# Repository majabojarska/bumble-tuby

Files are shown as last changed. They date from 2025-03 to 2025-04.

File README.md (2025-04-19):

# Bumble Tuby Guitar Amplifier




This is a relatively simple, hybrid guitar amplifier, made as a hobby project.
To me it's mostly about learning, having fun, and building something tangible.

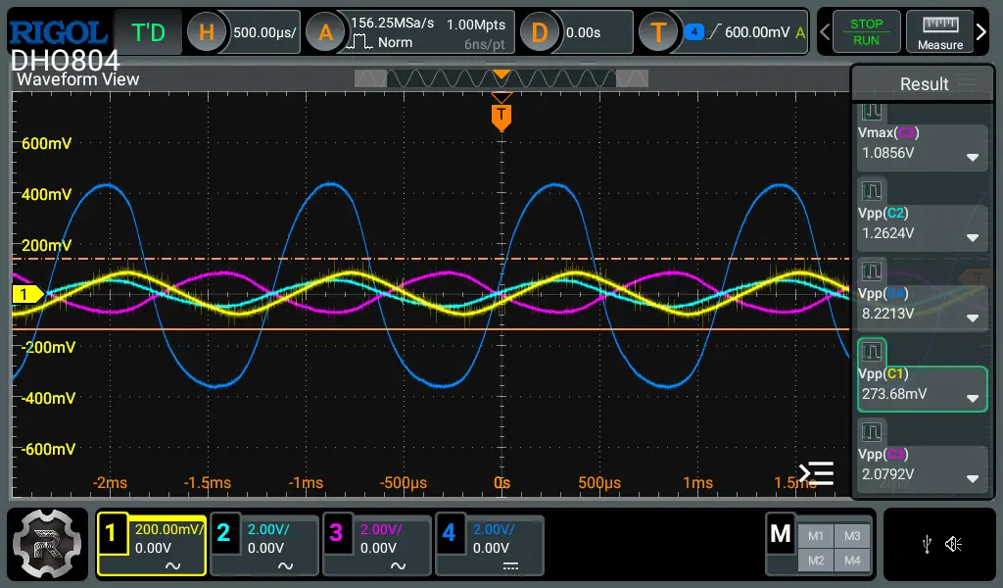
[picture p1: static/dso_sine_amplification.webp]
DSO capture of amplification stage outputs


## Features

- Runs off of a single 12V DC supply
- Pre-amp based on the 12AU7 vacuum tube
- FX loop
- Tone control section
- Line in
- Solid state power amplifiers (headphones, speaker)
  - Class D mono speaker amp
  - Class A stereo headphone amp

Schematic

### Bill of materials

> [!NOTE]  
> This section is yet to be populated.

## To-do

### Circuit design

- [x] Add headphone output.
- [x] Add effects loop:
  - FX send can be driven directly from the 2nd tube stage.
  - FX return needs a buffer before feeding into the power amp section. Can use the second half of the NE5532 for this.
  - What about operation modes? With/without effects loop. This would require a SPDT switch to either send the pre-amped signal into the effects chain, or directly into the buffer.
- [x] Add bypass capacitors on power supply lines:
  - LM386: 10uF, 100nF
  - opamps: 10uF, 100nF
- [x] Add power switch, LED
- [x] Consider poweramp alternatives
  - TPA3110
- [x] Make buffer bias voltage adjustable
- [x] Fix tube biasing
- [x] Buffer triode outputs (plates)
- [x] Mute speaker PA when headphone jack plugged in
- [x] Add headphone PA
- [x] Add gain adjustment for the power section (LM386 pins 1-8)
- [x] Split design into separate subschematics
  - How to express connections?
  - [Hierarchical sheets in KiCad](https://docs.kicad.org/9.0/en/eeschema/eeschema.html#drawing-hierarchical-sheets)
- [x] Add stereo line-in, [signal mixing](https://electronics.stackexchange.com/questions/103435/naively-mixing-two-or-perhaps-more-audio-signals)
- [x] Attenuate FX send 20x, and then on return amplify it by 20x
  - Floor pedals can't handle the 8Vpp the preamp outputs
  - The whole FX section should by itself have unity gain, if the send and return are shorted.
- [x] Add split-rail opamp bias source
- [ ] Split design into multiple sheets
- [ ] Add a tone control section.
  - Big muff style single-pot tone control seems nice and simple.
  - After tube, before output buffer? Alternatively, right after gain stage, before first triode.
- [ ] Add screw terminals for vacuum tube connections
- [ ] Does this require ripple rejection?
- [ ] Revisit tube input biasing, something seems off. Verify on breadboard.
- [ ] Simulate pre-amp in SPICE
- [ ] Design perfboard layouts

### CI

- [ ] Render BOM into README, as a Markdown table.
- [ ] Auto update schematic date during artifact update workflow.

## Credits

This design was inspired by:

- [Ruby Tuby](https://tagboardeffects.blogspot.com/2014/10/ruby-tuby.html)
  amplifier design.
- [Tube Cricket](https://beavisaudio.com/projects/TubeCricket/)

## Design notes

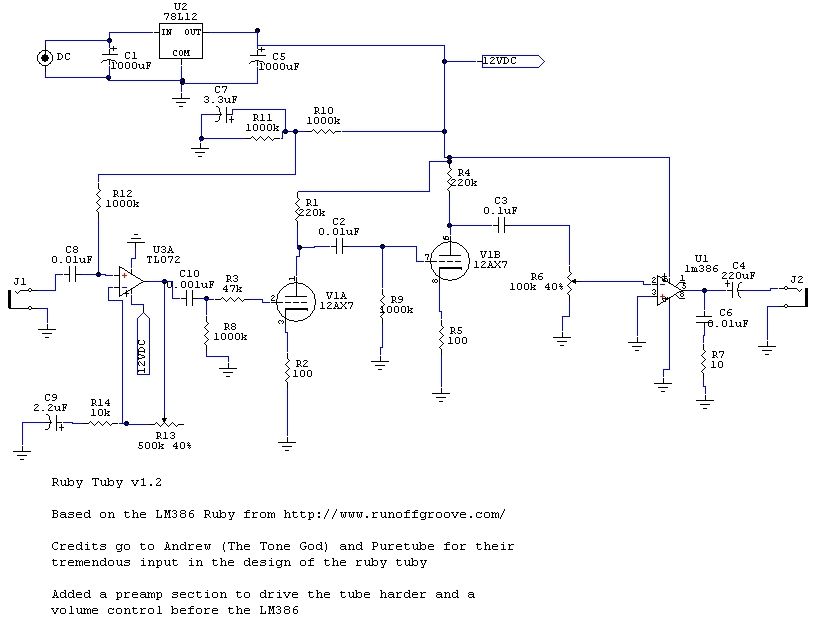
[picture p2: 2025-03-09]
static/ruby_tuby_original.jpg

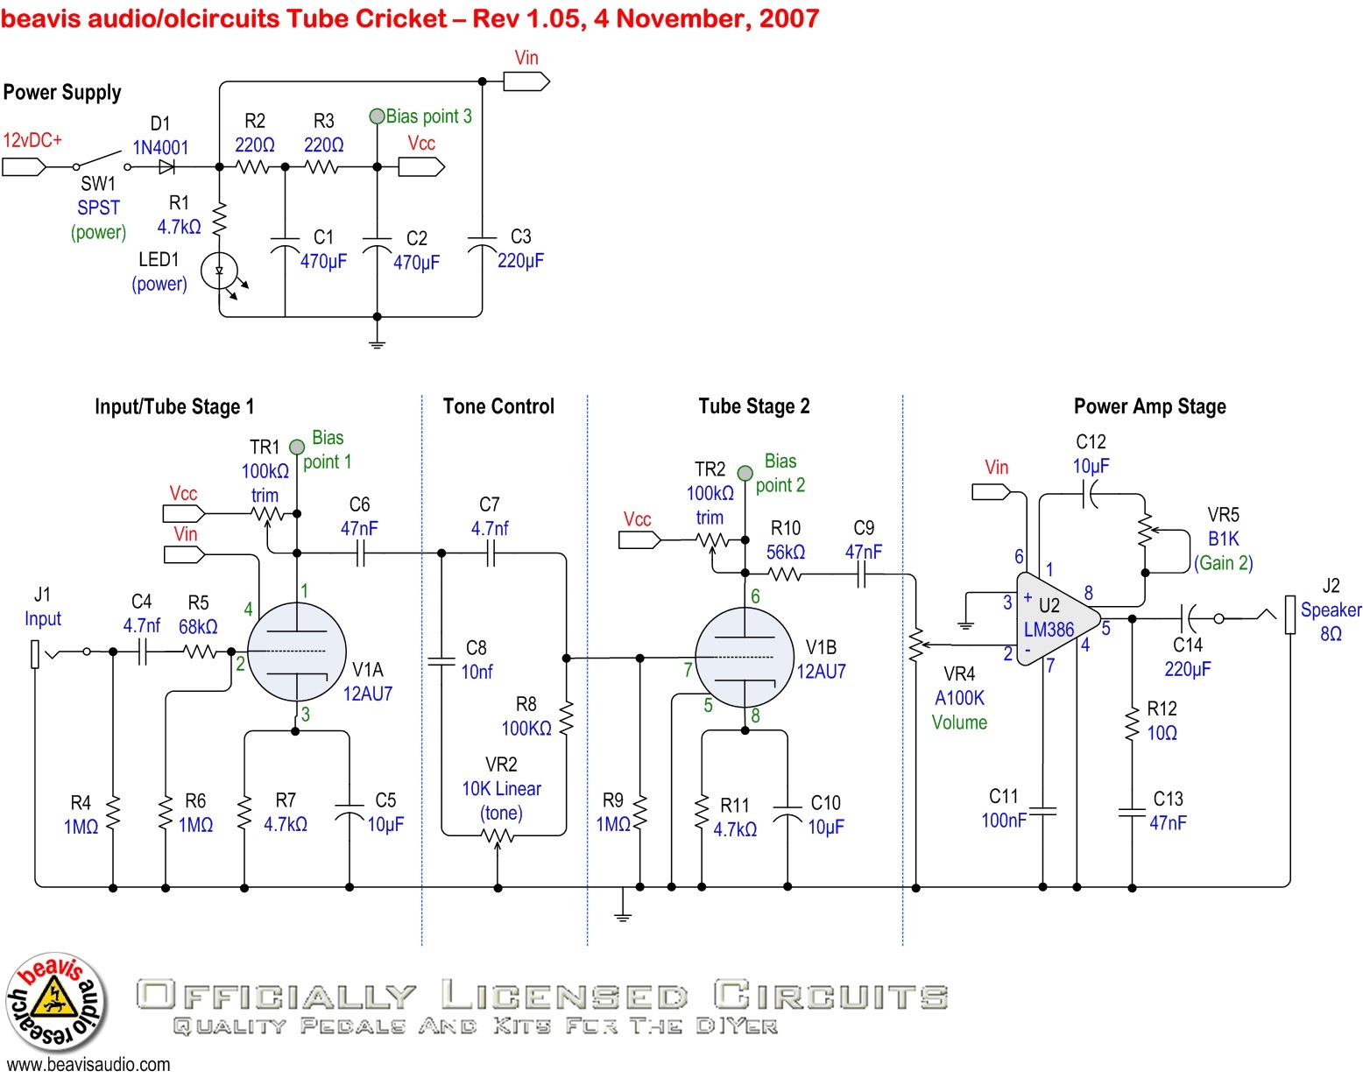
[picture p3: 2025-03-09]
static/tube_cricket.jpg

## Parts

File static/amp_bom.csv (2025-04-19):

Refs | Value | Footprint | Qty | DNP
C3,C4,C5,C6,C9,C29,C30 | 1uF |  | 7
C7,C10,C22,C25,C28 | 10uF |  | 5
C8,C11,C20 | 10nF |  | 3
C12,C13,C16,C17,C21,C27,C34 | 100nF |  | 7
C14,C15 | 100uF |  | 2
C18,C19 | 220uF |  | 2
C23,C24 | 47nF |  | 2
C26 | 2.2uF |  | 1
C33 | 1000uF |  | 1
D1 | LED amber |  | 1
D2 | LED blue |  | 1
J1 | LO Input |  | 1
J2 | Headphones |  | 1
J3 | HI Input |  | 1
J4 | Speaker 8Ω |  | 1
J5 | FX Send |  | 1
J6 | FX Return |  | 1
Q1 | S8050 |  | 1
R2,R12,R14,R16,R21,R25,R27,R31 | 1M |  | 8
R3,R4,R5,R6,R7,R8,R9,R10,R11,R18,R19,R29,R30,R35 | 10K |  | 14
R13,R15,R33,R34 | 220K |  | 4
R17,R32 | 4K7 |  | 2
R20,R22 | 47K |  | 2
R23,R24 | 10 |  | 2
R26,R28 | 100 |  | 2
RV2 | 50K log |  | 1
RV3 | 500K lin |  | 1
RV4 | 100K |  | 1
RV5 | 10k |  | 1
SW1 | PWR |  | 1
SW2 | FX Enable/Bypass |  | 1
U1,U2 | TL074 |  | 2
U3,U4 | LM386 |  | 2
U5 | ~ |  | 1
U6 | TL072 |  | 1
V1 | 12AX7 | Valve:Valve_Noval_P | 1

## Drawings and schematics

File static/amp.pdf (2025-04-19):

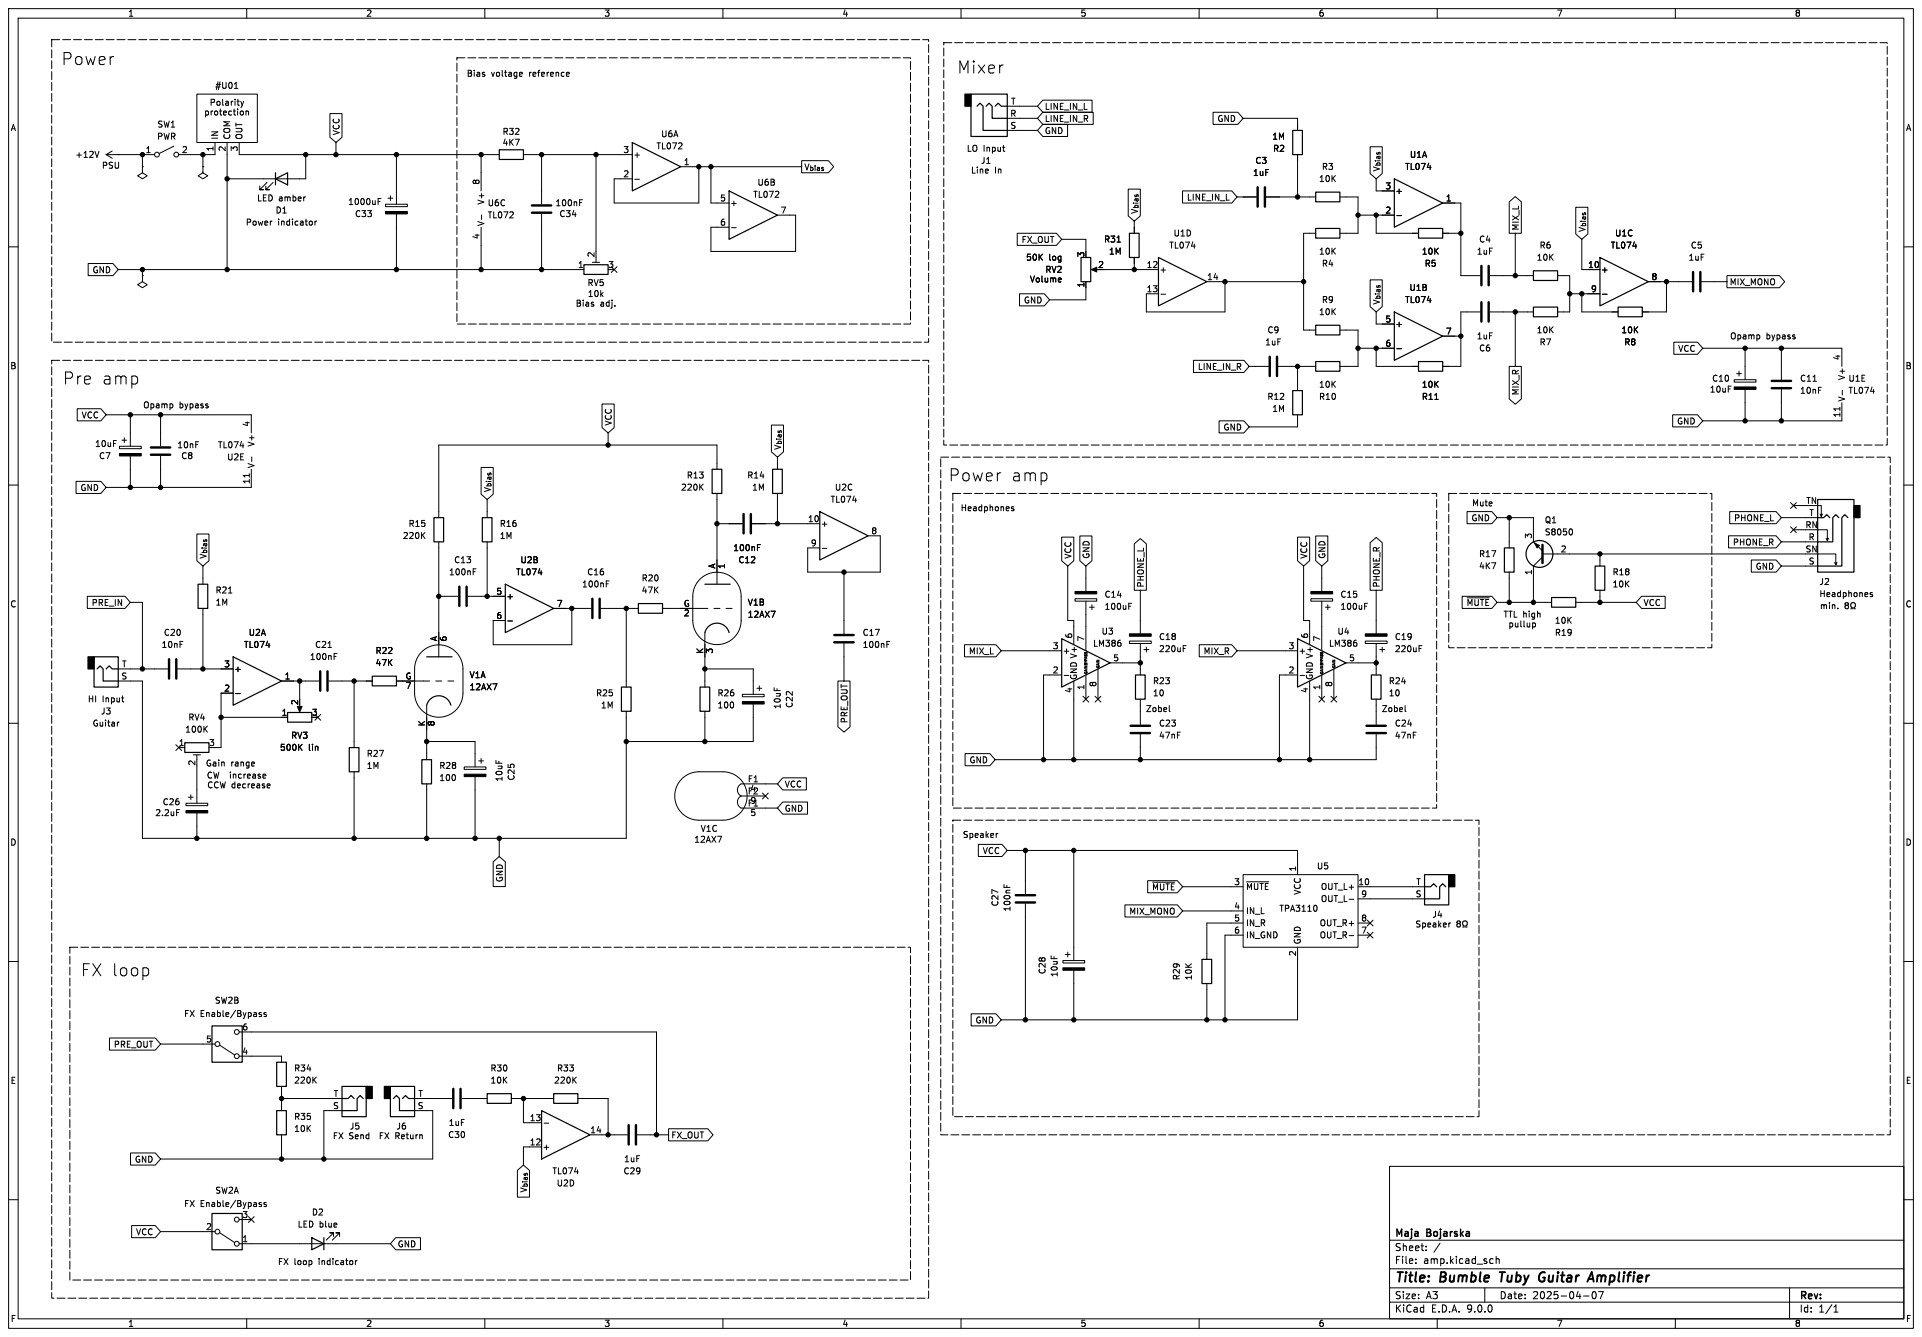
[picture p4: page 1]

Opamp bypass Zobel Mixer

LO Input Line In

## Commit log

2025-03-09 Initial circuit design (#2)
    - Adds project description in README.md
    - Populates schematic with initial circuit design
    - Includes headphone output
    - Adds future design to-dos
    - Credits other designs influencing this project
    - Extends ERC pre-commit triggers to any kicad file.
    [amp.kicad_pcb, amp.kicad_sch, amp_bom.csv]
2025-03-09 Improve artifact generation flow (#3)
    - Artifact generation opens a pull request instead of pushing to `main`.
    - The pull request is opened only if there are relevant changes. Non-relevant changes would be a diff consisting of "creation date" changes.
    - BOM generation also emits a markdown file containing the BOM table, generated from the CSV BOM.
2025-03-10 Add FX loop (#10)
    [amp.kicad_sch, amp_bom.csv]
2025-03-10 Add bypass caps (#11)
    [amp.kicad_sch, amp_bom.csv]
2025-03-11 Add power switch and led indicators (#12)
    Also replaces the FX loop SPDT switch with a DPDT, one for the signal,
    one for the LED indicator power.
    [amp.kicad_sch, amp_bom.csv]
2025-03-12 Schematic improvements (#14)
    - Replace remaining 12V with VCC
    - Schematic placement
    - TODO updates
    [amp.kicad_sch, amp_bom.csv]
2025-03-16 Add missing bias after FX loop return buffer (#15)
    [amp.kicad_sch, amp_bom.csv]
2025-03-16 Make diagrams black and white (#16)
    Better for printing and displaying on e-inks
2025-03-24 Fix: Remove bias after the FX loop return buffer (#17)
    [amp.kicad_sch, amp_bom.csv]
2025-04-03 Add TPA3110 module symbol (#18)
    ![image](https://github.com/user-attachments/assets/f8b43d61-f9f9-42f1-95b0-69642c91a372)
2025-04-04 Make input gain range adjustable (#19)
    ![image](https://github.com/user-attachments/assets/c34fa773-1671-44be-a96f-30affde28c4a)
    [amp.kicad_sch, amp_bom.csv]
2025-04-04 Use TL072 instead of NE5532 (#21)
    [amp.kicad_sch, amp_bom.csv]
2025-04-04 Make bias voltage adjustable (#22)
    ![image](https://github.com/user-attachments/assets/7d272d7a-218c-4b01-b36d-8e7ddcb458f7)
    [amp.kicad_sch, amp_bom.csv]
2025-04-04 Use TPA3110 (#23)
    ![image](https://github.com/user-attachments/assets/09bd7c46-21d9-4840-b3ab-6c87bac1cede)
    [amp.kicad_sch, amp_bom.csv]
2025-04-04 Fixup TPA3110 changes - botched wiring (#24)
    [amp.kicad_sch]
2025-04-04 Buffer triode outputs (#25)
    ![image](https://github.com/user-attachments/assets/d7fb1445-c9db-46b0-b5f0-927bbe05cb8b)
    [amp.kicad_sch, amp_bom.csv]
2025-04-05 Use TL074 instead of 2xTL072 for preamp (#28)
    [amp.kicad_sch, amp_bom.csv]
2025-04-05 Mute speaker PA when headphones are plugged in (#29)
    Also includes some layout/readability improvements
    [amp.kicad_sch, amp_bom.csv]
2025-04-05 Add amplification stage DSO capture image to README (#30)
2025-04-06 Add polarity protection (#33)
    Also adds a bunch of layout reworks, uses netlist labels.
    [amp.kicad_sch]
2025-04-06 Split sections, label I/O netlists (#34)
    [amp.kicad_sch, amp_bom.csv]
2025-04-06 Headphone PA, line-in support, active signal mixing, (#35)
    [amp.kicad_sch, amp_bom.csv]
2025-04-06 Fix input opamp gain pot type (log->lin) (#38)
    [amp.kicad_sch, amp_bom.csv]
2025-04-06 Fix U1A output coupling pot 1->10nF (#39)
    [amp.kicad_sch, amp_bom.csv]
2025-04-08 Move opamp bias source to power section (#41)
    ![image](https://github.com/user-attachments/assets/52923ac5-943d-44d2-a7b1-d4a0f699007a)
    [amp.kicad_sch, amp_bom.csv]
2025-04-08 Replace 2xNE5532 in mixer with 1xTL074 (#42)
    [amp.kicad_sch, amp_bom.csv]
2025-04-08 Update KiCad artifacts (#40)
    ## Beep boop, fresh artifacts 🤖.
    KiCad project sources have changed, fresh artifacts incoming ♻️!
    Auto-generated by [create-pull-request][1]
    [1]: https://github.com/peter-evans/create-pull-request
2025-04-08 Improve tube biasing (#49)
    Try out Tube Cricket style tube biasing
    https://beavisaudio.com/projects/TubeCricket/
    [amp.kicad_sch, amp_bom.csv]
2025-04-08 Update KiCad artifacts (#50)
    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
2025-04-19 Fixes prototype (#51)
    Okay so around a week ago I made some changes in my breadboard
    prototype, applied some of them here, got a week-long break, and now I
    barely remember what happened. Fortunately, the SVG diff and commit
    history explain a lot, so here it goes:
    - Fixes tube biasing, or at least gets it to a much better place. The
    previous plate/cathode resistors configuration caused the triode outputs
    to be way too biased towards `VCC`, resulting in a narrow dynamic range
    and causing the tube stages to clip easily against the ceiling.
    - FX loop:
    - send is now attenuated by 22x and amplified by 22x upon return. This
    is due to the preamp reaching close to $10V_{pp}$, which most pedal
    effects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
    [amp.kicad_sch, amp_bom.csv]
2025-04-19 Update KiCad artifacts (#52)
    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
2025-04-19 Active opamp bias voltage reference (#53)
    Reworks the bias reference voltage dividers into a single, opamp-based
    voltage reference. Should supply up to around 6mA. As long as
    high-impedance biasing is done, this is fine. Currently the circuit
    biases signal lines via 1Mohm resistors, each of which would sink <10uA,
    worst case scenario.
    [amp.kicad_sch, amp_bom.csv]
2025-04-19 Update KiCad artifacts (#54)
    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
